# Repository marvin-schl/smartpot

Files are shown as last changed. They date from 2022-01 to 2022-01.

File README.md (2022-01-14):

# SmartPot

SmartPot ist ein RaspberryPi Projekt um einen smarten Blumentopf/Gewächshaus umzusetzen. Es werden alle für 
Pflanzen wichtigen Parameter (Temperatur, Luft-/Bodenfeuchtigkeit und Lichtstärke) gemessen und 
auf verschiedenen Wegen zur Verfügung stellt. Die Visualisierung der Daten kann über einen Webserver des 
Raspberry Pi´s aufgerufen und analysiert werden. Alternativ können die Sensorwerte auch per 
Telegram manuell erfragt werden. Außerdem können für alle Parameter kritische Schwellenwerte programmiert werden, bei deren 
Unter- bzw. Überschreiten eine Benachrichtigung über Telegram abgeschickt wird.
Im Folgenden wird die Umsetzung des Projektes detailliert dokumentiert, sodass mit Hilfe dieser 
Anleitung ein Nachbau des SmartPots möglich wird. Es werden alle Softwareeinrichtungsschritte von der Erstellung des Telegram Bots bis zur Node-RED Einrichtung erklärt. Außerdem werden Schaltpläne bereitgestellt welche auf die Softwareimplementationen angepasst sind. Zusätzlich zu den Schaltplänen wird ebenso ein Leiterplattenlayout, sowie alle benötigten Komponenten zum Bestücken der Leiterplatte mit einer Preisübersicht zur Verfügung gestellt.

Schaltungsseitig sind zur Zeit folgende Funktionalitäten implementiert:

- ein auf den RaspberryPi steckbares Shield mit integrierterm 12V/5V Linearregler zur Spannungsversorgung des Pi´s
- Anbindung eines Temperatur/Luftfeuchtigkeitssensors (DHT11/DHT22)
- Anbindung eines Bodenfeuchtigkeitssensors
- Anbindung eines Lichtsensors
- Drei schaltbare 12V/1,5A Leistungsausgänge mit PWM Unterstützung

Softwareseitig ist die aktuelle Version des SmartPots beinhaltet folgende Funktionen:

- _Temperatur_ messen, überwachen, auslesen und ausgeben
- _Luftfeuchtigkeit_ messen, überwachen,  auslesen und ausgeben
- _Bodenfeuchtigkeit_ messen, überwachen, auslesen und ausgeben
- _Lichtstärke_ messen, überwachen, auslesen und ausgeben
- Kommunikationsinterface über Telegram Web
- Node-RED Visualisierung der Sensorwerte (historisch/live)

Die Idee einen intelligenten Blumentopf zu entwickeln wurde durch zahlreiche Anleitungen aus dem
Web inspiriert (Bspw: [Automatisches Gewächshaus](https://tutorials-raspberrypi.de/automatisches-raspberry-pi-gewaechshaus-selber-bauen/)).

Der modulare Aufbau dieses Projektes eignet sich sehr gut für Gruppenarbeiten und kann dem
jeweiligen Wissensstand (Programmierung vom Raspberry Pi) durch Variation der
Funktionskomplexität angepasst werden.

In zukünftigen Versionen könnte unter einer optimierten Ausnutzung der verfügbaren Leistungsausgänge und Erweiterung von finanziellen Mitteln weitere Funktionen wie z.B. automatische Bewässerung, Lichtregelung sowie Belüftung realisiert werden, um so den Automatisierungsgrad weiter zu erhöhen.

## Gliederung

Diese Dokumentation glieder sich in folgende Schritte an denen unter Anderem die Inbetriebnahme des SmartPots erläutert wird:

1. Die Erstellung eines Telegram Bots 
2. Die Konfiguration des Telegram Bots für den SmartPot
3. Die Einrchtung von Node Red und der SmartPot Software selber 
    - 3.1 als manuelle Einichtung **oder**
    - 3.2  als automatische Einrchtung via docker und docker-compose
4. Die Bereitstellung der Schaltpläne und eines Leiterplattenlayout, zum Nachbau auf einem Bredboard oder zur Fertigung einer Leiterplatte, inklusive Stückliste aller benötigten Komponenten
5. Einer kurzen Übersicht der enthaltenen Klassen und Methoden 
6. Eine Übersicht, welche bekannten Schwachstellen und Verbesserungsideen für zukünftige Versionen des SmartPots existieren

## 1. Einrichtung des TelegramBots

Zunächst muss ein Chat mit dem Telegram-Bot „BotFather“ wie folgt erstellt werden:
Bei Telegram im Suchfeld „BotFather“ eingeben und unter Chats den BotFather auswählen.

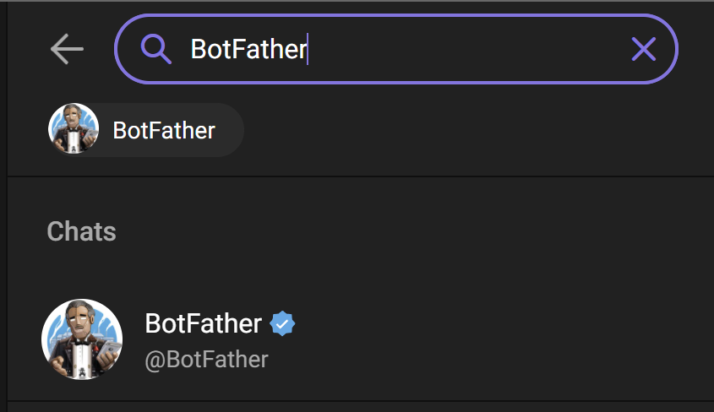
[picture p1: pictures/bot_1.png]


Im Chat des BotFathers kann nun ein Chatbot erstellt werden:

1. /newbot eingeben
2. Botname vergeben
3. Username vergeben
4. Bot-Token kopieren
5. Link für Chatbot anklicken

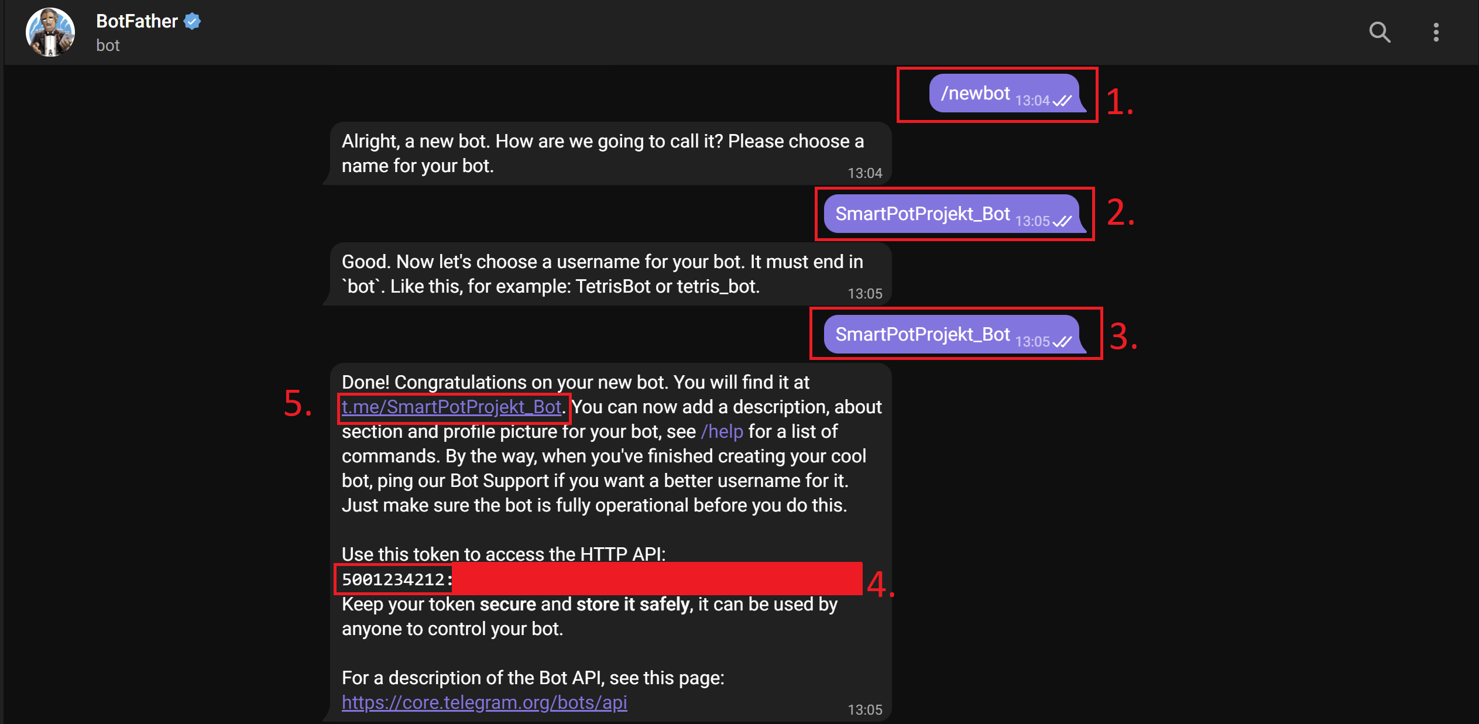
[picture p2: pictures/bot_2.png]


Zum Abfragen neuer Nachrichten muss im Browser folgende Website aufgerufen werden:

https://api.telegram.org/botReplaceThisWithTheBotFatherToken/getUpdates

In Telegram Web dem erstellten Chatbot eine Nachricht senden. 

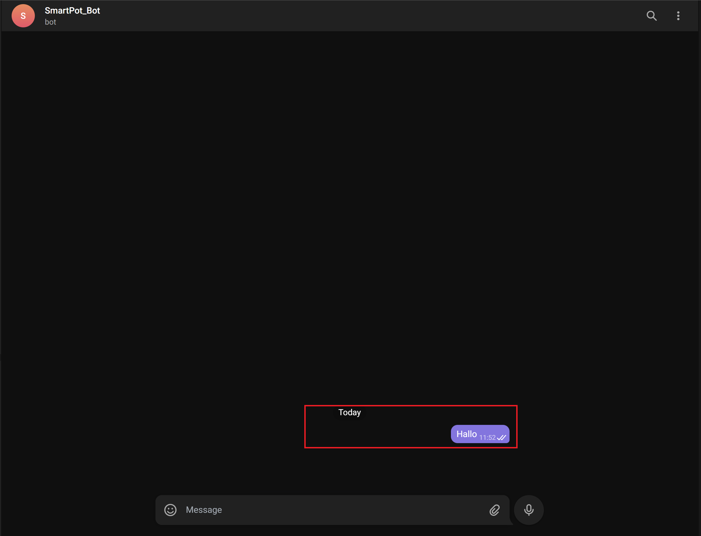
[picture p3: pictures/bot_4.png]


Nach Neuladen der Website kann nun aus der geschickten Nachricht die Chat-ID
ermittelt werden.



(Optional) Um den Chatbot einer Gruppe hinzufügen zu können, muss folgende Konfiguration im
BotFather vorgenommen werden:

1. /setprivacy eingeben
2. @Botname eingeben
3. Disable eingeben

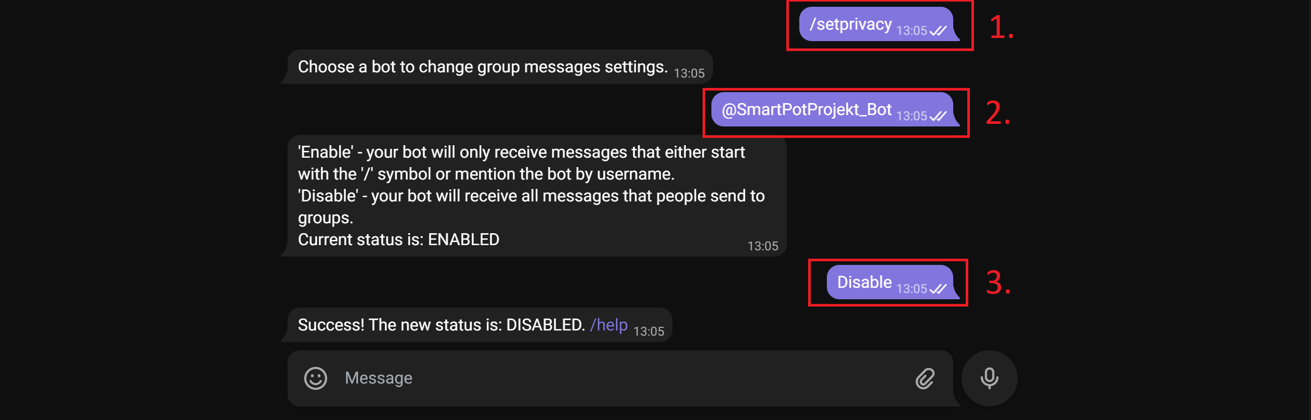
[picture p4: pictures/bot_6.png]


***Achtung:** Wenn sich der Chatbot in einer Gruppe befindet, muss die Chat-ID der Gruppe verwendet werden!*

## 2. Konfiguration des SmartPots

Es wird davon ausgegangen, dass auf dem RaspberryPi ein neu installiertes RaspianOS basierend auf Debian Buster installiert, ein Zugang zum Internet, sowie ein ssh Zugang vorhanden ist. Zunächst muss dieses Repository auf dem RaspberryPi geclonet werden:

    git clone https://git.haw-hamburg.de/aco732/smartpot.git

Für die Konfiguration steht eine smartpot.ini Datei zur Verfügung. 

``` ini
#############################################
# Smart Pot Version 1 - Configuration File  #
#############################################

[Telegram]

#Sets the telepot API token
chattoken = <your-token>

#Sets the telepot Chat-ID
chatid = <your-chat-id>

[Logging]

# Sets the loglevel, when not specified DEBUG is taken
# Possible Values: INFO, WARN, ERROR, DEBUG
level = DEBUG

# If set to 1 the logs will be printed on sys.stdout
stdout = 1

# Sets the logfile
# Comment out to deactivate Logfile
file = smartpot.log

[Soil Moisture]
# This section calibrates the soil moisture sensor. Keep in mind that any calibration action will only effect the
# python software. Depending on the Calibration it is possible that the Node-RED settings have to updated manually

# Calibration of the soil moisture sensor connected to adc channel 1.
# The calibrated output value is calculated from the Output value out [V]  follows:
#     calibrated_out = scaling*(out - offset)
# Calibration procedure:
#    1.) Set both Values to zero.
#    2.) Connect the sensor and make sure it's 100% dry.
#    3.) Measure the voltage offset and adjust offset_calibration value to get an calibrated_out of 0.
#    4.) Pull the sensor onto a defined soil moisture level.
#    5.) Adjust scaling in such a way that calibratet_out matches the desired value.
# Default calibration is between 0 and 100% -> max Voltage 1.9V -> sclaing=100/1.9=52.6315
offset = 0.0
scaling = 52.6315

# Defines the level at which calibrated_out is going into saturation. Comment out
# to disable saturation.
saturation = 100

# Defines the unit of the measured and calibrated value. Percent Symbols have to be escaped with another percent symbol.
unit = "%%"

[Light]
# This section calibrates the light sensor. Keep in mind that any calibration action will only effect the
# python software. Depending on the Calibration it is possible that the Node-RED settings have to updated manually.

# Calibration of the light sensor connected to adc channel 2.
# The calibrated ouput value is calculated from the Output value out [V] as follows:
#     calibrated_out = scaling*(out - offset)
# Calibration procedure:
#    1.) Set both Values to zero.
#    2.) Connect the sensor and make sure it's completly dark.
#    3.) Measure the voltage offset and adjust offset_calibration value to get an calibrated_out of 0.
#    4.) Pull the sensor onto a defined brightness level.
#    5.) Adjust scaling in such a way that calibratet_out matches the desired value.
# Default calibration is between 0 and 100% -> max Voltage 1.8V -> sclaing=100/1.9=55.555
offset = 0.0
scaling = 55.555

# Defines the level at which calibrated_out is going into saturation. Comment out
# to disable saturation.
saturation = 100

# Defines the unit of the measured and calibrated value. Percent Symbols have to be escaped with another percent symbol.
unit = "%%"

```

In der Konfiguationsdatei müssen nun der zuvor ermittelte Telegram API-Token unter chattoken und die ermittelte Chat-ID unter chatid eingetragen werden. Außerdem können das Log-Level, das Ausgabeformat der Logs und die Kalibration der analogen Sensoren angepasst werden. 

Alternativ kann das setup.sh Skript ausgeführt werden, um die Telegram Konfiguration durchzuführen. Auf die abschließende Frage, ob der SmartPot via docker-compose gestartet werden soll, muss in diesem Fall mit "n" geantwortet werden:

    bash setup.sh

## 3.1 manuelle Einrichtung des RaspberryPi's

Zuerst müssen über Python Paketmanager pip folgende Pakete installiert werden.

    pip3 install RPi.GPIO Adafruit_DHT smbus2 telepot

Desweiteren wird eine [Library für den MCP3426](https://github.com/coburnw/MCP342x) für den MCP3426 verwendet. Diese ist bereits in den Source Files enthalten.

### Einrichten von Node-RED

Das Installation von Node-RED erfolgt durch folgende Shell-Eingabe:

    bash <(curl -sL https://raw.githubusercontent.com/node-red/linux-installers/master/deb/update-nodejs-and-nodered) --node16

Das Node-RED Dashboard zur Visualisierung der Sensorwerte wird mit folgender Eingabe installiert:

    npm i node-red-dashboard

Zusätzlich müssen in den Node-RED Einstellungen Parameter konfiguriert werden:

    cd ~/.node-red
    nano settings.js

@Line 253: „//“ entfernen

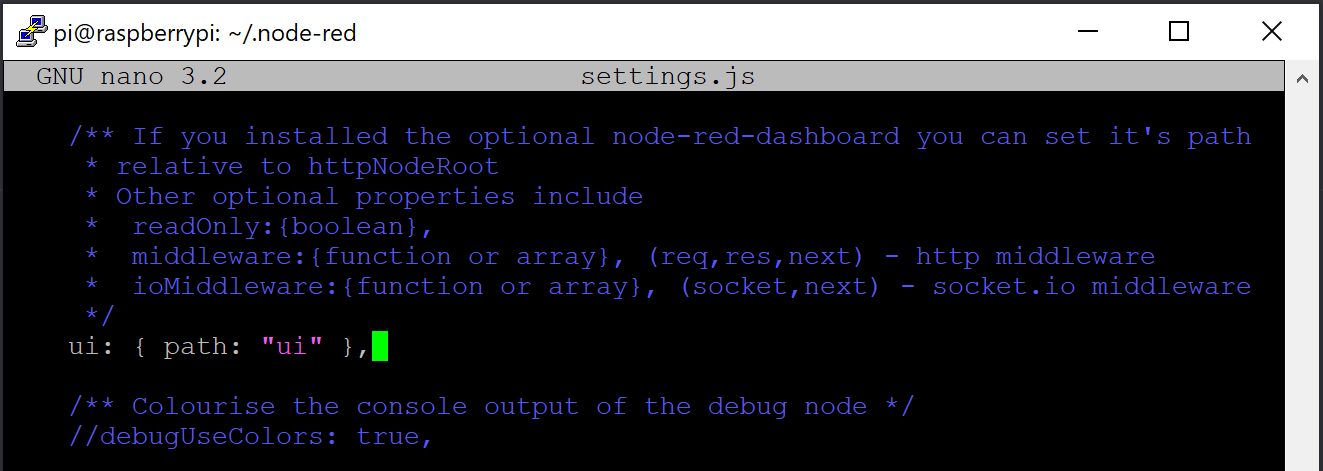
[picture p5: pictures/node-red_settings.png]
node-red_settings


Um Node-RED bei Systemstart automatisch auszuführen wird folgender Befehl verwendet:

    sudo systemctl enable nodered.service

Der Node-RED Editor ist über die IP-Adresse des Pi´s aufzurufen. Die IP wird wie folgt angezeigt:

    hostname -l

Node-RED ist standardmäßig auf Port 1880 erreichbar. Mit dem im vorherigen Schritt ermittelten <hostname> kann die Node-RED Konfiguration unter folgender Adresse im Interetbrowser aufgerufen werden:
    
    http://<hostname>:1880

Die vorbereitete Node-RED Visualisierung kann nun wie folgt installiert werden:

1. Menü-Reiter auswählen
2. Palette verwalten klicken

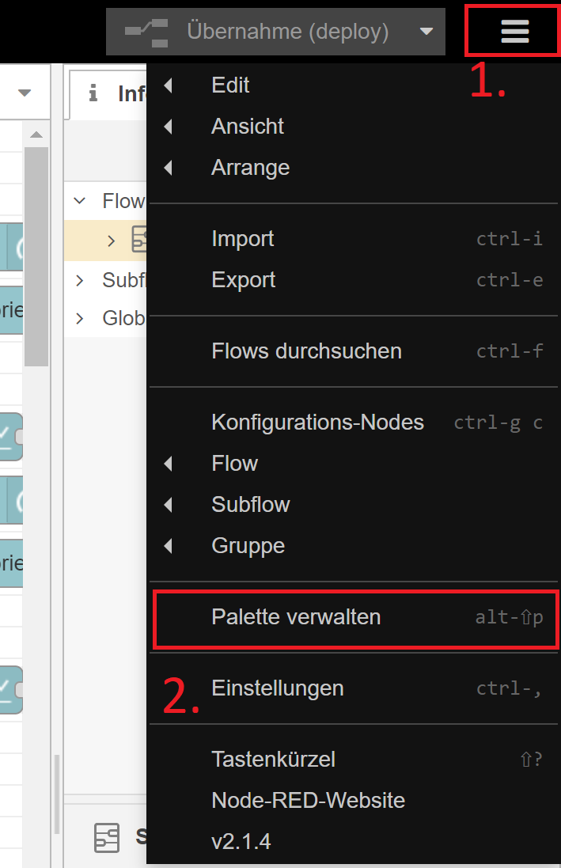
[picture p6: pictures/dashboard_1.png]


3. „Dashboard“ in Suchfeld eingeben
4. Auf „Installieren“ klicken

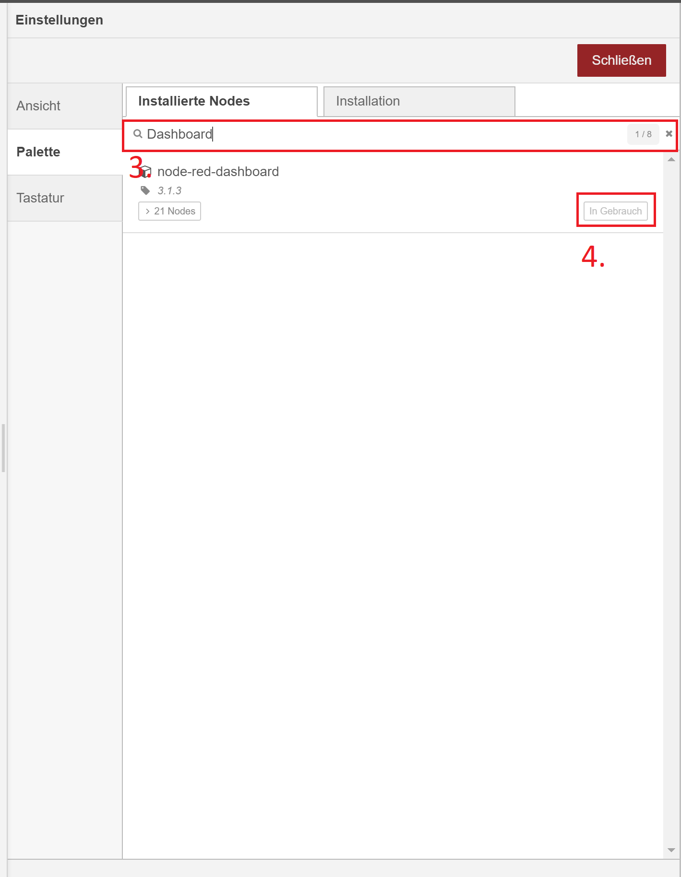
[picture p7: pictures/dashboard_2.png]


Die zur Verfügung gestellte Visualisierung des Node-RED Dashboards muss nun wie folgt kopiert werden:

    cp /home/pi/smartpot/resources/flows.json /home/pi/.node-red/lib/flows

Abschließend wird die flow-Datei in Node-RED importiert:

1. Menü-Reiter auswählen
2. Import klicken

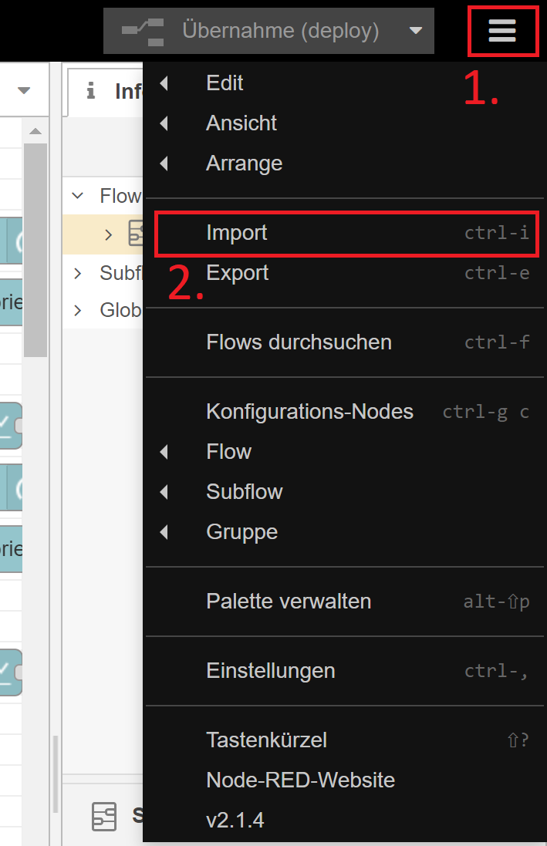
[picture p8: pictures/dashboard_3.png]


3. Lokal auswählen
4. „flows.json“ wählen

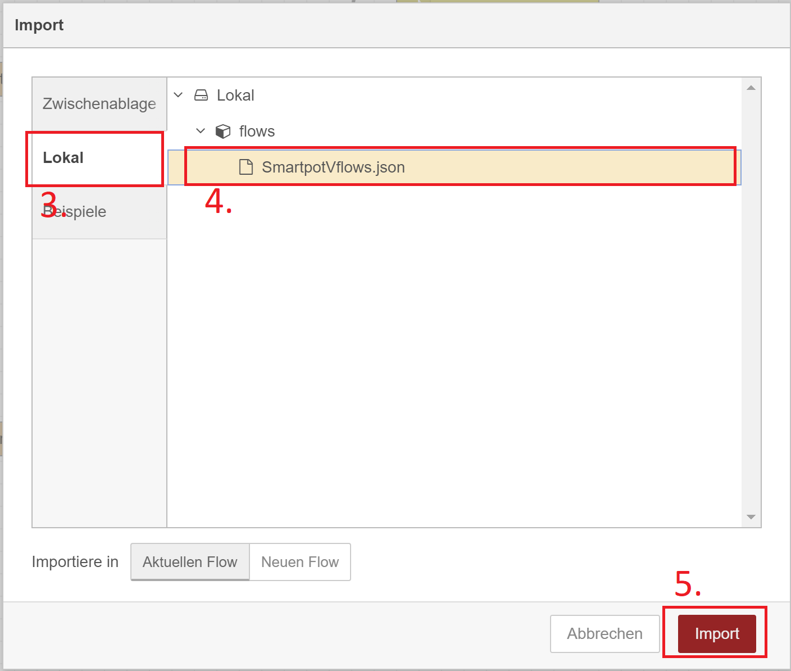
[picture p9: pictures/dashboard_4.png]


5. Auf „Import“ klicken
6. „Übernahme (deploy)“ klicken

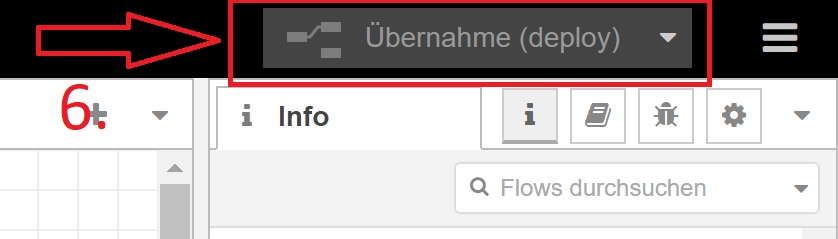
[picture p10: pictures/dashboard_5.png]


Die Visualisierung kann nun unter 

    http://<hostname>:1880/ui

erreicht werden.

## 3.2 automatische Einrichtung des RaspberryPi's via Docker

Falls docker und docker-compose bereits installiert sein sollten kann der nächste Schritt übersprungen werden und direkt mit "Starten der Smartpot Umgebung" fortgefahren werden.

### Einrichtung von docker und docker-compose

Für die Einrichtung von docker und docker-compose müssen folgende Befehle ausgeführt werden.

    sudo apt-get update
    curl -sSL https://get.docker.com | sh
    sudo apt-get install docker-compose
    sudo usermod -aG docker pi

Nachdem der letzte Befehl ausfgeführt worden ist muss der Pi neugstartet werden.

   sudo reboot

### Starten der Smartpot Umgebung

Vor dem ersten Start muss die setup.sh ausgeführt werden. Diese stellt sicher, dass die ini, log und csv Dateien vorhanden sind und die Telegrameinstellungen getätigt worden sind. Außerdem stellt diese sicher, dass die Container mit ausreichenden Rechten gestartet werden:
    
    bash setup.sh
    
Der SmartPot kann gleich im Anschluss darauf us dem Skript heraus gestartet werden. **Sollte der Start nicht direkt aus der setup.sh erfolgen muss zuerst ein Neustart oder Neulogin durchgeführt werden!**
Aus dem SmartPot Verzeichnis kann nach Neustart/Neulogin in Zukunft der SmartPot wie folgt gestartet werden:

    docker-compose up
    
Um den SmartPot als Hintergrunddienst laufen und automatisch starten zu lassen, muss zusätzlich das Flag -d/--detached (losgelöst) verwendet werden:
    
    docker-compose up -d

## 4. elektronischer Aufbau

Schaltplan des RaspberryPi Shields:

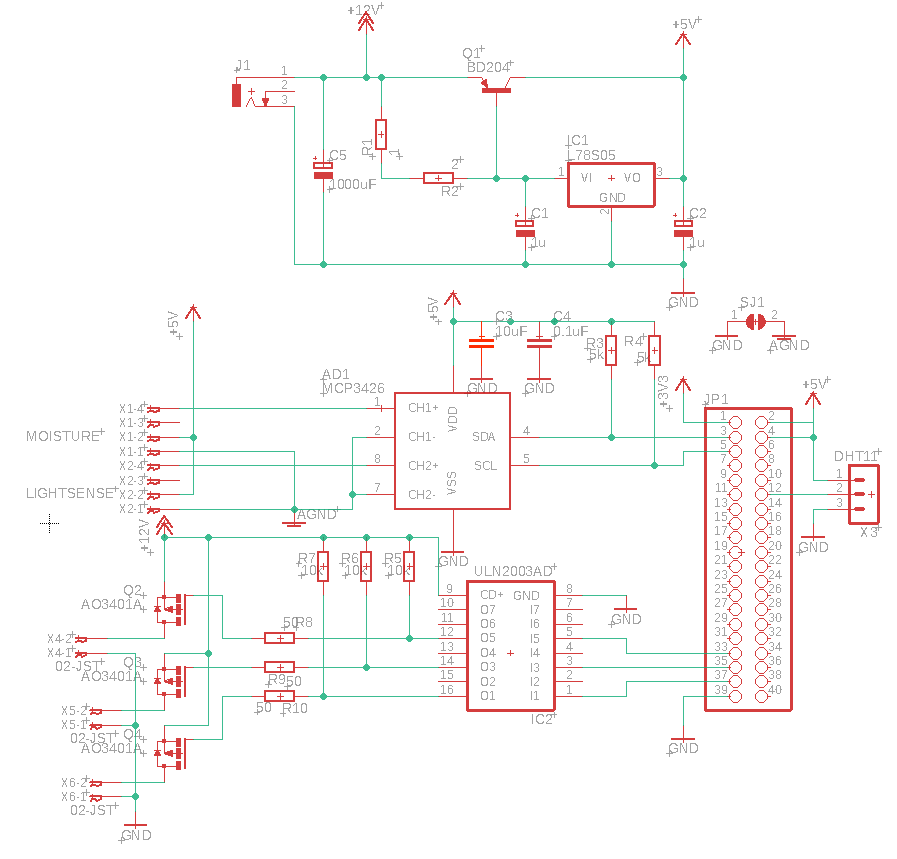
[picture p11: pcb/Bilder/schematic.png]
Schaltplan


Die Schaltung kann an einem handelsüblichen 12V Netzteil betrieben werden. Über einen 12V/5V Linearregler (uA78S05)
wird die Versorgnungsspannung für den RaspberryPi bereit gestellt. Auf dem Board ist eine dreipolige Buchsenleiste für einen DHT11 bzw DHT22 Sensor vorgesehen. Der Sensor kann einfach auf die Buchsenleiste gesteckt (Sensorseitig zur Platinenmitte zeigend) werden und per OneWire Protokoll ausgelesen werden. Für den analogen Lichtsensor und den analogen Bodenfeuchtigkeitssensors ist ein 2 Kanal Delta-Sigma AD-Wandler mit I2C Interface, der MCP3426, verbaut. Die drei Leistungsausgänge werden von drei P-Kanal Mosfets (AO3401A) geschaltet. Die Gate Signale werden durch einen Darlington-Array (ULN2003AD) getrieben, welches die Rohsignale des RaspberryPi verstärkt.
    
Für einen Betrieb des SmartPots über ein Bredboard muss in der aktuellen Version des SmartPots lediglich der DHT mit J1-12 und der MCP3426, zusätzlich zu seiner äußeren Beschaltung, mit den I2C-Pins J1-3 und J1-5 verbunden werden. Dann können die Sensoren analog zum o.g. Schaltplan ausgelesen werden. 
    
Die hier verwendeten analogen Sensoren geben Spannungen bis zu 4,2V  aus. Der MCP3426 kann an seinen differentiellen Eingängen jedoch nur Spannungen zwischen +-2,048V messen. Zur Reduktion der Eingangsspannung auf ein für den MCP3426 optimierten Spannungsniveau kann ein 1:1 Spannungsteiler (bswp: 10k-10k) verwendet werden. Dieser ist in den akuellen Schaltplänen und der Platine noch nicht vorgesehen. Aus diesem Grund wurde der Spannungsteiler in den beiden Sensorkabeln des Licht- und des Bodenfeuchtigkeitssensors verbaut.

Das dazugehörige Layout wurde wie folgt umgesetzt:

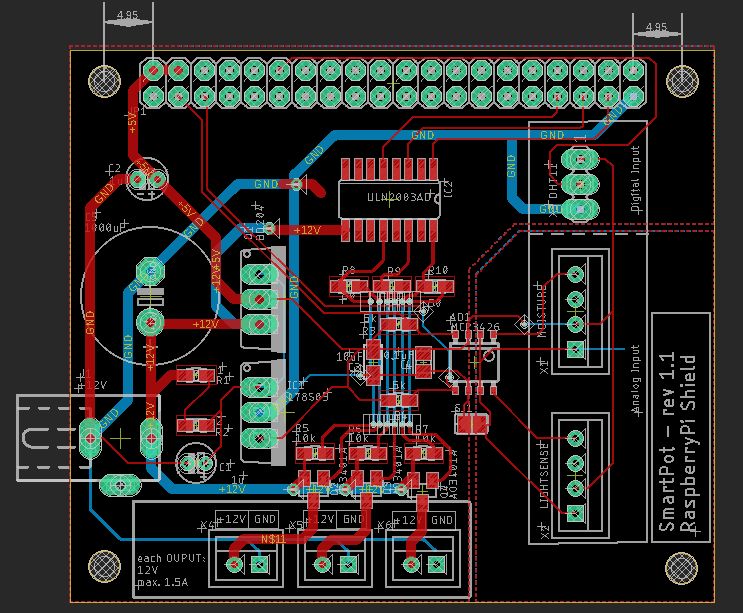
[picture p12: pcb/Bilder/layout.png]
Layout


### Stückliste

Position    |Bezeichnung                        | Anzahl  |Stückpreis €| Positionspreis €
------------|-----------------------------------|-------- |------------|-----------------
1           | RaspberryPi 3B                    |1        |39,4        | 39,4
2           | RaspberryPi Staking Header        |1        |1,6         | 1,60
3           | ULN2003AD                         |1        |0,75        | 0,75
4           | 10k Kohleschichtwiderstand        |4        |0,1         | 0,4
5           | RPI LK Kabel 50                   |2        |2,75        | 5,50
6           | MCP3426                           |1        |3,10        | 3,10
7           | uA78S05                           |1        |0,45        | 0,45
8           | BD204                             |1        |0,41        | 0,41
9           | AO3401A                           |3        |0,25        | 0,75
10          | Widerstand 0805 1,0               |1        |0,03        | 0,03
11          | Widerstand 0805 2,0               |1        |0,02        | 0,02
12          | Widerstand 0805 51,0              |3        |0,02        | 0,06
13          | Widerstand 0805 5k                |2        |0,03        | 0,06
14          | Widerstand 0805 10k               |3        |0,03        | 0,09
15          | Keramikkondensator 0805 100nF     |1        |0,02        | 0,02
16          | Tantalkondensator 1210 10uF       |1        |0,32        | 0,32
17          | Elektrolytkondensator 2mm 1uF     |2        |0,02        | 0,04
18          | Elektrolytkondensator 5mm 1mF     |1        |0,29        | 0,29
19          | JST XH2P ST Buchse                |3        |0,20        | 0,60
20          | JST XH4P ST Buchse                |2        |0,25        | 0,50
21          | 3fach Buchsenleiste 2,54mm        |1        |0,14        | 0,14
22          | DC Buchse 2.1mm                   |1        |1,20        | 1,20
23          | DHT11                             |1        |4,50        | 4,50
24          | Joy-It Linker Kit Lichtsensor     |1        |1,01        | 1,01
25          | Joy-it sen-Moisture Sensorkit     |1        |4,99        | 4,99
26          | Leiterplatte                      |1        |2,00        | 2,00
27          | Gesamt                            |         |            | 68,23

(Reichelt Preise beispielhaft, Stand 06.01.22)

## 5. Software Implementation

Nachfolgend soll eine Klassenreferenz augestellt werden. Die einen Überblick über die implementierten Klassen und deren Methoden gib. Für eine genauere Beschreibung bitte die Methoden Kommentare beachten. Dort werden die einzelnen Argumente genauer beschrieben. 

**monitor.HysteresisMonitor**:
Diese Klasse implementiert die nicht blockierende Überwachung einer Ausgangsgröße. Es kann eine Funktion übergeben werden, welche den zu überwachenden Wert zurückgibt, ein oberer Grenzwert und ein unterer Grenzwert. Außerdem kann für das überschreiten des oberen und das unterschreiten des unteren Grenzwerts jeweils eine Callback Funktion übergeben werden. Diese Klasse erbt von threading.Thread. Eine Beispielhafte Verwendung dieser Klasse ist in example.py gegeben.

Öffentliche Methoden:
- start()
- stop()
- run()

**mointor.TimeBasedMonitor**:
Diese Klasse implementiert die nicht blockierende Überwachung einer Ausgangsgröße. Es kann eine Funktion übergeben werden, die die zu überwachende(n) Größe(n) zurückgibt. Diese Klasse erbt von threading.Thread. Eine Beispielhafte Verwendung dieser Klasse ist in example.py gegeben.

Öffentliche Methoden:
- start()
- stop()
- run()

**src.smartpot.SmartPot**:
Diese Klasse implementiert eine physikalische Repräsentation des SmartPots an sich und dient als Interface zum Backend. Es sind drei Konstanten vorhanden SmarPot.smarpot.SmartPot.X4, SmarPot.smarpot.SmartPot.X5 und SmarPot.smarpot.SmartPot.X6. Diese referenzieren die Leistungsausgänge auf dem SmartPot Raspberry Shield rev 1.1 und können den output_* Methoden als pin übergeben werden.
Öffentliche Methoden:
- output_on(pin)
- output_off(pin)
- output_pwm_on(pin, freq, dc)
- output_pwm_off(pin)
- output_pwm_change_freq(pin, freq)
- output_pwm_change_dc(pin, dc)
- read_temperature()
- read_humidity()
- read_light_intensity()
- read_soil_moisture()

**src.dht.DHT**:
Diese Klasse wrapped die Adafruit_DHT Library und stellt einen objektorientierten Zugriff zur Verfügung. Es kann bei der instanziierung festgelgt werden ob es sich um einen DHT11 oder DHT22 handelt.

Öffentliche Methoden:
- read_temperature()
- read_humidity()

**src.adc.MCP3426**:
Diese Klasse wrapped die verwendete [MCP342x](https://github.com/coburnw/MCP342x) Library für die hier benötigete Anwendung.

Öffentliche Methoden:
- read_ch1()
- read_ch2()

**src.output.PowerOutputPin**:
Diese Klasse verwendendet das RPi.GPIO Modul und implementiert die Funktionen der Leistungsausgänge. 

Öffentliche Methoden
- on()
- off()
- start_pwm(freq, dc)
- stop_pwm()
- change_freq(freq)
- change_dc(dc)

## 6. Ausblick

Hier werden bekannte Schwächen der aktuellen Version des SmartPots sowies des dazugehörige Shield aufgelistet, welche in folgenden Versionen überarbeitet werden sollten.

- Der Linearregler auf der pcb wird bei Betrieb mit einem 12V Netzteil und hohen Stromverbräuchen des Raspberrys sehr warm. Hier wäre eine Spannungswandlung über einen Schaltregler zu bevorzugen.

- Beim Ausschalten der Leistungsausgänge, also wenn das Gatesignal der Ausgangsmosfets (Q2, Q3, Q4) von 0V auf 12V gezogen wird. Findet die Entladung der Gatekapazität im unbelaseten Zustand über die Pullup Widerstände (R5, R6, R7) statt. Dies führt zumidest im unbelasteten Zustand zu sehr hohen Abfallszeit des Ausgangssignals. Ein Ansatz wäre kleinere Pullup Widerstände zu verwenden auf Kosten einer höheren Stromaufnahme bei eingeschaltetem Ausgang. Ein anderer Ansatz wäre die verwendung einer richtigen Mosfet Endstufe.

- In dem jetzigen Design wurden die positiven und negativen Ch2 Eingangspins des MCP3426 vertauscht. Die folgliche invertiert gemessene Spannung wurde Softwareseitig kompensiert.
    
- Die Ausgangssignale der analog Sensoren sind bis zu 4V hoch. Der MCP3426 kann jedoch nur +-2,048V messen. Eine Lösuing wäre ein auf der Leiterplatte befindlicher 1:1 Spannungsteiler, ein anderer AD-Wandler oder besser an den AD-Wandler angepasste Sensoren.

- Eine Verbesserung des Automatisierungsgrades durch die Nutzung der Hardwareseitig implementierten Schaltfunktionen

- Eine Erweiterung der Node-RED Oberflächen, sodass nicht nur ein passives Monitoring sondern auch eine aktive Kontrolle des SmartPots möglich ist

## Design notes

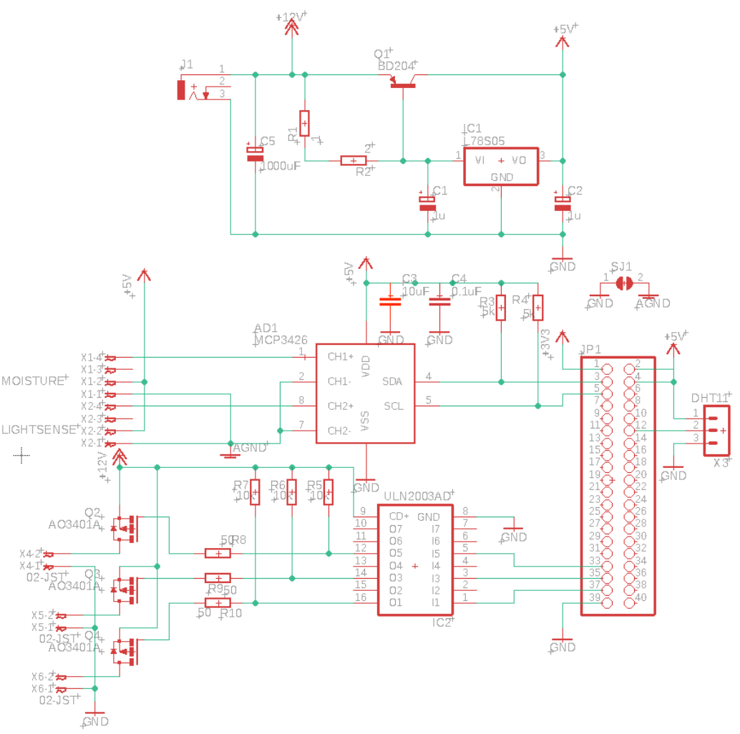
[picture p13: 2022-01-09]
pictures/schaltplan_platine.PNG

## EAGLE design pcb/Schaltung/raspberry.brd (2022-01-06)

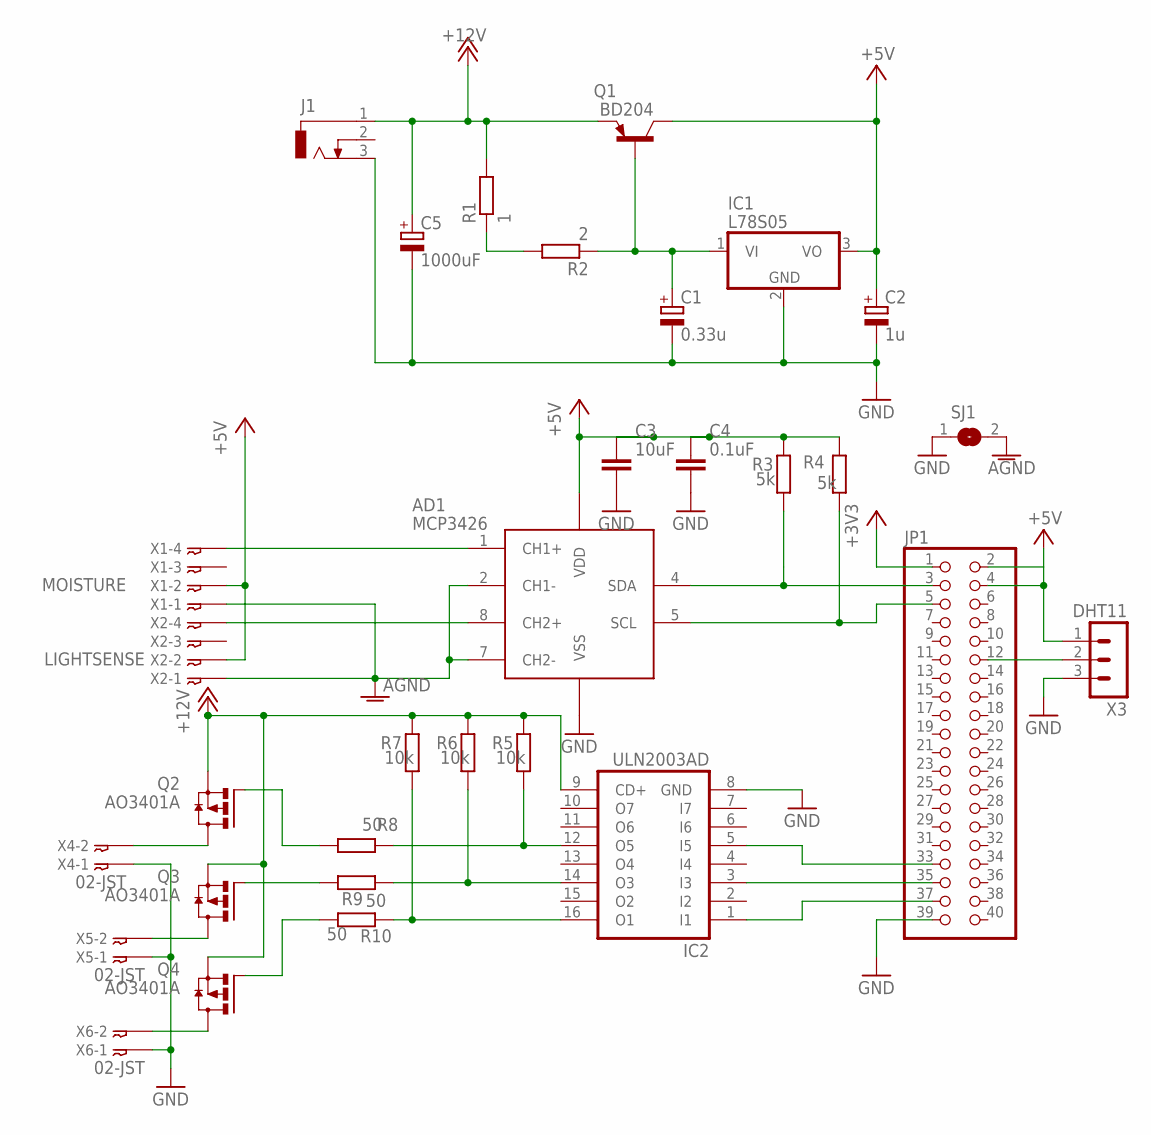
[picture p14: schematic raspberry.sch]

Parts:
AD1: MCP3426; SO-8
C1: 0.33u; E1,8-4
C2: 1u; E2-4
C3: 10uF; CAPM3216X180
C4: 0.1uF; CAPC2012X110
C5: 1000uF; E5-13
IC1: L78S05; TO220V
IC2: ULN2003AD; SO16
J1: DCJ0303
JP1: PINHD-2X20; 2X20
Q1: BD204; TO220V
Q2, Q3, Q4: AO3401A; SOT23
R1: 1; R0805W
R2: 2; R0805W
R3, R4: 5k; R0805W
R5, R6, R7: 10k; R0805W
R8, R9, R10: 50; R0805W
SJ1: SJ
X1: MOISTURE; B4B-XH
X2: LIGHTSENSE; B4B-XH
X3: DHT11; MA03-1
X4, X5, X6: 02-JST; B2B-XH

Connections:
+3V3: JP1.1
+5V: AD1.3 (VDD), C2.+, C3.1, C4.1, IC1.3 (VO), JP1.2, JP1.4, Q1.2 (C), R3.1, R4.1, X1.P$2, X2.P$2, X3.1
+12V: C5.+, IC2.9 (CD+), J1.1, Q1.3 (E), Q2.2 (S), Q3.2 (S), Q4.2 (S), R1.2, R5.1, R6.1, R7.1
AGND: AD1.2 (CH1-), AD1.7 (CH2-), SJ1.2, X1.P$1, X2.P$1
GND: AD1.6 (VSS), C1.-, C2.-, C3.2, C4.2, C5.-, IC1.2 (GND), IC2.8 (GND), J1.3, JP1.39, SJ1.1, X3.3, X4.P$1, X5.P$1, X6.P$1
GPIO18-DHT11-DATA: JP1.12, X3.2
unnamed: R1.1, R2.2
unnamed: AD1.4 (SDA), JP1.3, R3.2
unnamed: C1.+, IC1.1 (VI), Q1.1 (B), R2.1
unnamed: AD1.5 (SCL), JP1.5, R4.2
unnamed: AD1.8 (CH2+), X2.P$4
unnamed: AD1.1 (CH1+), X1.P$4
unnamed: IC2.1 (I1), JP1.37
unnamed: Q3.3 (D), X5.P$2
unnamed: Q4.3 (D), X6.P$2
unnamed: IC2.3 (I3), JP1.35
unnamed: Q2.3 (D), X4.P$2
unnamed: IC2.16 (O1), R7.2, R10.1
unnamed: Q2.1 (G), R8.2
unnamed: IC2.5 (I5), JP1.33
unnamed: Q3.1 (G), R9.2
unnamed: IC2.12 (O5), R5.2, R8.1
unnamed: IC2.14 (O3), R6.2, R9.1
unnamed: Q4.1 (G), R10.2

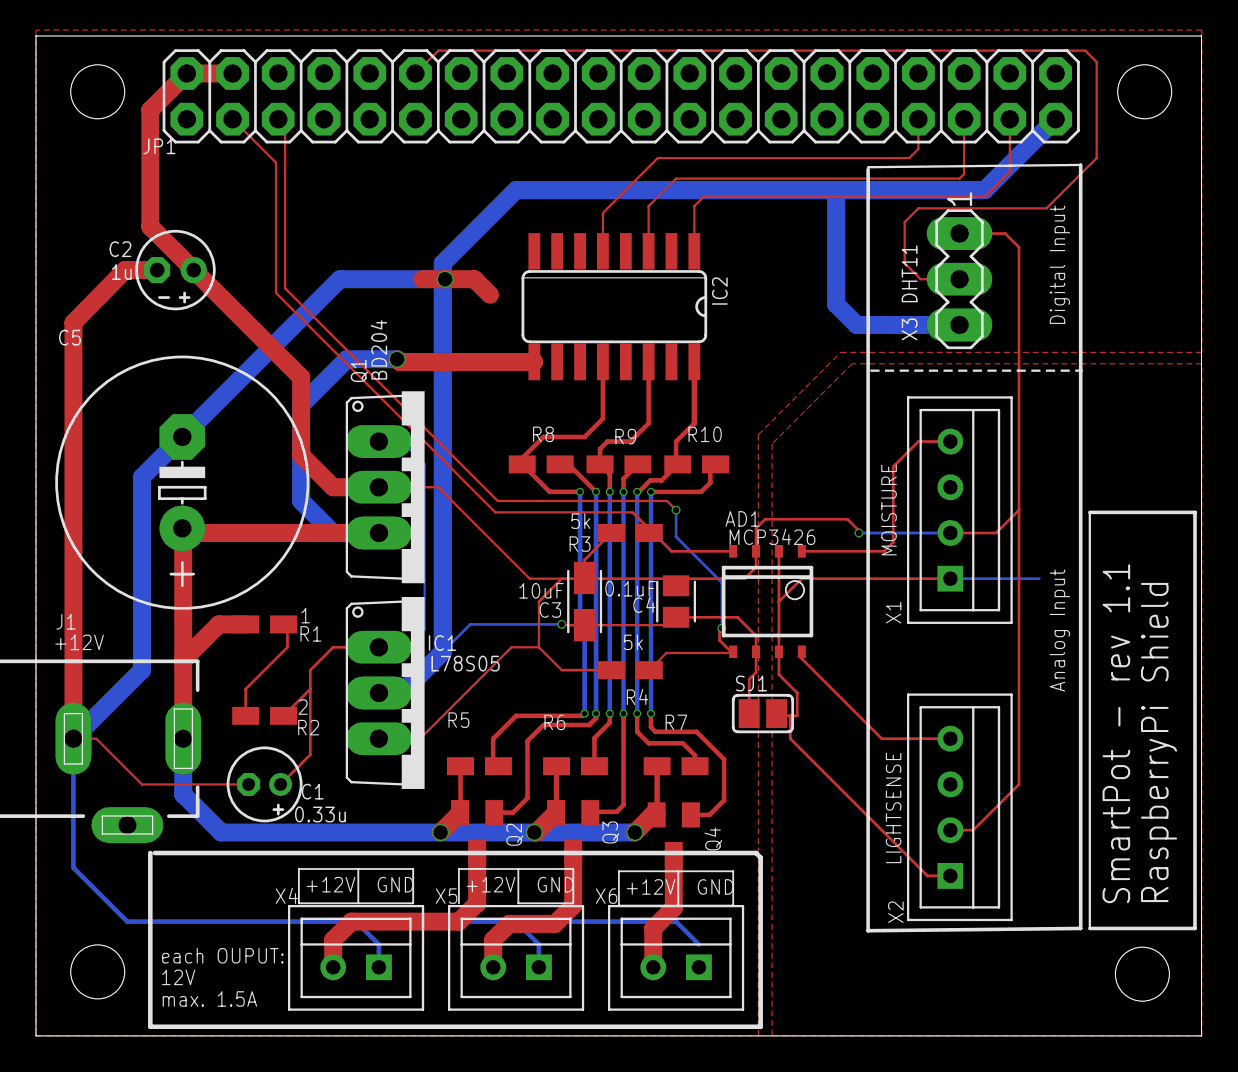
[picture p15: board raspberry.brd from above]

Board: 2 copper layers, 64.8 x 55.5 mm, 31 parts (0 on the bottom side), 23 nets.

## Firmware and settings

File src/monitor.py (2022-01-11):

import time
from datetime import datetime
from threading import Thread
from abc import ABC, abstractmethod
import logging
import configparser
#setup config
config = configparser.ConfigParser()
config.read("smartpot.ini")
#setup logger
# get root Logger
log = logging.getLogger()

class Monitor(Thread, ABC):
    """
    Implements a abstract monitor. This class handles every action all monitors have in common. Namely this is the
    retrieving of the monitored value, retrieving a timestamp and waiting the cycle time repeatedly until the stop method
    is called.
    """
    def __init__(self, name, getter, cycle_time):
        """
        Initilizes a new Monitor.
        :param name: A String representation of the value that is monitored. Mainly for logging purposes.
        :param getter: A callable which return value should be the value of the monitored variable.
        :param cycle_time: Time to wait beween retrieving new values in seconds. Default value is 0.1s.
        """
        super().__init__()
        self.__getter = getter
        self.__name = name
        self.__cycle_time = cycle_time
        self.__running = False

    @property
    def running(self):
        return self.__running

    @property
    def name(self):
        return self.__name

    def start(self):
        """
        Starts the run() method in a new Thread.
        :return: None
        """
        self.__running = True
        log.info(type(self).__name__.__str__() + " - Starting Monitor for " + self.__name + " in a new Thread...")
        super().start()

    def stop(self):
        """
        Stops the running Monitor Thread.
        :return: None
        """
        self.__running = False
        log.info(type(self).__name__.__str__() + " - Stopping Monitor for " + self.__name + "...")

    def run(self,*args,**kwargs):
        #do as long as self.__running is true
        while self.__running:
            val = self.__getter()
            now = datetime.now()
            self.handle(val,now)
            # wait the cycle time until next value is retrieved
            time.sleep(self.__cycle_time)
        log.info(type(self).__name__.__str__() + " - Monitor for " + self.__name + " stopped...")

    @abstractmethod
    def handle(self, val, now):
        """
        The specific handling of the monitored value. Has to be implemented by the subclass.
        :param val: Monitored Value
        :param now: Timestamp
        :return:
        """
        pass

class HysteresisMonitor(Monitor):

    def __init__(self,name,getter,thres,callback_up_thres,lower_thres = None,callback_lw_thres = None,cycle_time = 0.1):
        """
        Initilizes a new HysteresisMonitor class. A callback is called by this class as soon as a defined threshold value
        is exceeded. Optionally a second callback can be passed when the monitored value falls below a lower threshold.
        :param name: A String representation of the value that is monitored. Mainly for logging purposes.
        :param getter: A callable which return value should be the value of the monitored variable.
        :param thres: The upper threshold.
        :param callback_up_thres: A callable which is called when getter() > thres.
                                    Signature should be: `callback_up_thres(name, val, thres, timestamp)`
        :param lower_thres: (optionally) A lower threshold value. Default value is equal to thres.
        :param callback_lw_thres: (optionally) A callable which is called when getter() < lower_thres. When not passed nothing is executed.
                                    Signature should be: `callback_lw_thres(name, val, thres, timestamp)`
        :param cycle_time: (optionally) Time to wait beween retrieving new values in seconds. Default value is 0.1s.
        """
        log.info("Initiliazing Monitor for "+ name + ".")
        super().__init__(name, getter, cycle_time)
        self.__thres = thres
        self.__lw_thres = self.__thres if lower_thres == None else lower_thres
        if self.__lw_thres > self.__thres:
            log.warning(type(self).__name__.__str__() + " - Lower Threshold for Value " + self.name + " of "
                            + str(self.__lw_thres)+ "is greater than upper threshold of " + str(self.__thres) + ".")
        self.__callback_up_thres = callback_up_thres
        self.__callback_lw_thres = callback_lw_thres
        self.__reported = False
        log.info(type(self).__name__.__str__() + " - Successfully initilized " + self.name + " Monitor.")


    def handle(self, val, now):
        """
        Hanlde method which is does the actual handling of the monitored value.
        :param val: Monitored Value
        :param now: Timestamp
        :return: None
        """
        if val > self.__thres and self.__reported == False:
            # do this if self.__thres is exceeded for the first time, do some logging
            log.info(type(self).__name__.__str__() + " - Value "+ self.name + "=" +str(val)+ "passed upper threshold of " + str(self.__thres) + " at " + str(now) +".")
            #call the callback
            self.__callback_up_thres(now, val, self.__thres, self.name)
            #set reported to True to make sure that the callback is not called every single cycle while val is greater than threshold
            self.__reported = True
        if val < self.__lw_thres and self.__reported == True:
            # do this if a exceed was reported and the val falls bellow lower threshold
            # reset the reported value so next up_threshold exceed will be reported and do some logging
            self.__reported = False
            log.info(type(self).__name__.__str__() + " - Value "+ self.name + "=" + str(val) + "passed upper threshold of " + str(self.__lw_thres) + " at " + str(now) +".")
            # if a callback is provided for this case, execute in
            if self.__callback_lw_thres != None:
                self.__callback_lw_thres(now, val, self.__lw_thres, self.name)


class TimeBasedMonitor(Monitor):

    def __init__(self, name, getter, callback, cycle_time):
        """
        Initilizes a new TimeBasedMonitor. A TimeBasedMonitor monitors a specific variable by retrieving its value
        in defined time steps.

        :param name: A String representation of the value that is monitored. Mainly for logging purposes.
        :param getter: A callable which return value should be the value of the monitored variable.
        :param callback: A callback functioin which is called every cycle.
                            Signature should be: `callback(name, val, timestamp)`
        :param cycle_time: Time to wait beween retrieving new values in seconds.
        """
        log.info(type(self).__name__.__str__() + " - Initiliazing Monitor for "+ name + ".")
        super().__init__(name, getter, cycle_time)
        self.__callback = callback
        log.info(type(self).__name__.__str__() + " - Successfully initilized " + name + " Monitor.")


    def handle(self, val, now):
        """
        Hanlde method which is does the actual handling of the monitored value.
        :param val: Monitored Value
        :param now: Timestamp
        :return: None
        """
        #do some logging and exceute the callback
        log.info(type(self).__name__.__str__() + " - Read Value for " + self.name + "="+str(val)+" at "+ str(now)+".")
        self.__callback(now, val, self.name)


if __name__=="__main__":

    x = 0
    thres = 12

    def get_x():
        return x

    def callback(timestamp, value, threshold, name):
        print("Value "+ name + "=" +str(value)+ "passed threshold of " + str(threshold) + " at " + str(timestamp) +".")

    def callback2(now, val, name):
        print(str(now) + " - " +name+"="+str(val))

    log.info("Starting Monitors...")
    m = HysteresisMonitor("x", get_x, thres, callback, callback_lw_thres=callback)
    m2 = TimeBasedMonitor("x", get_x, callback2, 1)
    m.start()
    m2.start()


    log.debug("Starting counting up...")
    while x < 14:
        x += 0.3
        time.sleep(0.2)
    log.debug("Starting counting down...")
    while x >= 0:
        x -= 0.3
        time.sleep(0.2)

    m.stop()
    m2.stop()
    m.join()
    m2.join()

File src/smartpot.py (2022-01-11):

from src.adc import MCP3426
from src.dht import DHT
from src.output import PowerOutputPin
from src import logging_conf_setup
import logging
import configparser

#setup logger for the first time
logging_conf_setup.setup()
#setup config
config = configparser.ConfigParser()
config.read("smartpot.ini")
#setup logger
# get root Logger
log = logging.getLogger()


class SmartPot:
    """
    This class represents a physical SmartPot rev1.1. It handles the simple functions like controlling single outputs,
    reading temperature, humidity, light intensity and soil moisture values.
    """

    X4 = 13
    X5 = 19
    X6 = 26
    pin_names = {13:"X4",19: "X5" ,26: "X6"}

    def __init__(self, dht_type = "DHT11"):
        """
        Creates a new instance of a SmartPot. The implementation is threadsafe.
        :param dht_type: (optional) "DHT11" or "DHT22" depending on the connected DHT sensor. Default Value is "DHT11".
        """
        power_pins = [SmartPot.X4, SmartPot.X5, SmartPot.X6]
        dht_pin = 18
        adc_bus = 1
        log.info(type(self).__name__ + " - Initializing ADC on Bus Number " + adc_bus.__str__())
        self.__adc = MCP3426(adc_bus)
        log.info(type(self).__name__ + " - Initializing "+dht_type+" on pin "+dht_pin.__str__()+"...")
        self.__dht = DHT(dht_pin, dht_type)

        log.info(type(self).__name__ + " - Initializing PowerOutputPins X4,X5 and X6...")
        self.__power_pins = {}
        for pin in power_pins:
            self.__power_pins[pin] = PowerOutputPin(pin)
        log.info(type(self).__name__ + " - SmartPot initalized")


    def output_on(self, pin):
        """
        Sets an power output HIGH
        :param pin: SmartPot.X4, SmartPot.X5 or SmartPot.X6
        :return: None
        """
        log.info(type(self).__name__ + " - Turning PowertOuput "+ SmartPot.pin_names[pin]+" on.")
        self.__power_pins[pin].on()

    def output_off(self, pin):
        """
        Sets an power output LOW
        :param pin:  SmartPot.X4, SmartPot.X5 or SmartPot.X6
        :return: None
        """
        log.info(type(self).__name__ + " - Turning PowertOuput "+SmartPot.pin_names[pin]+" off.")
        return self.__power_pins[pin].off()

    def output_pwm_on(self, pin, freq, dc):
        """
        Starts a PWM on an power output.
        :param pin: SmartPot.X4, SmartPot.X5 or SmartPot.X6
        :param freq: Frequency in Hertz
        :param dc: Duty Cycle in percent
        :return: None
        """
        log.info(type(self).__name__ + " - Turning PWM at "+SmartPot.pin_names[pin]+" on. f=" +str(freq)+"Hz, dc="+str(dc)+"%")
        return self.__power_pins[pin].start_pwm(freq, dc)

    def output_pwm_off(self, pin):
        """
        Stops a PWM on an power output
        :param pin: SmartPot.X4, SmartPot.X5 or SmartPot.X6
        :return: True if successfull, False if no PWM was started yet
        """
        log.info(type(self).__name__ + " - Turning PWM at "+SmartPot.pin_names[pin]+" off.")
        return self.__power_pins[pin].stop_pwm()

    def output_pwm_change_freq(self, pin, freq):
        """
        Changes PWM Frequency of an power output
        :param pin: SmartPot.X4, SmartPot.X5 or SmartPot.X6
        :param freq: New frequency in Hertz
        :return: True if successfull, False if no PWM was started yet
        """
        log.info(type(self).__name__ + " - Changing  PWM Frequency at "+SmartPot.pin_names[pin]+" to f="+str(freq)+"Hz.")
        return self.__power_pins[pin].change_freq(freq)

    def output_pwm_change_dc(self, pin, dc):
        """
        Changes the duty cycle of an power output
        :param pin: SmartPot.X4, SmartPot.X5 or SmartPot.X6
        :param dc: New duty cycle in percent
        :return: True if successfull, False if no PWM was started yet
        """
        #no dc cycle change logging because -> eventually overloading the logfile
        #log.debug("Changing PWM DC at "+SmartPot.pin_names[pin]+" to dc="+str(dc)+"%.")
        return  self.__power_pins[pin].change_dc(dc)

    def read_temperature(self):
        """
        Reads the temperature of an connected DHT sensor.
        :return: Temperature in degree celsius
        """
        log.info(type(self).__name__ + " - Start temperature measurement.")
        temp = self.__dht.read_temperature()
        log.info(type(self).__name__ + " - Temperature measurement finished at "+str(temp)+"'C.")
        return temp

    def read_humidity(self):
        """
        Reads the humidity  of an connected DHT sensor.
        :return: relative humidity in percent
        """
        log.info(type(self).__name__ + " - Start humidity measurement.")
        hum = self.__dht.read_humidity()
        log.info(type(self).__name__ + " - Humidity measurement finished at "+str(hum)+"%.")
        return hum

    def read_light_intensity(self):
        """
        Reads the value of the light intensity sensor and applies calibration of INI File.
        :return: Light intensity value according to calibration values in INI File.Default
        calibration should return percentage of maximum measureable light intensity value.
        """
        log.info(type(self).__name__ + " - Start light intensity measurement.")

        #get the adc value in volts
        intensity = self.__adc.read_ch2()

        if intensity != -999:
            # calibrate
            scale = float(config["Light"]["scaling"])
            offset = float(config["Light"]["offset"])
            intensity = scale*(intensity - offset)

        #apply saturation if configured
        if "saturation" in config["Light"]:
            saturation = float(config["Light"]["saturation"])
            intensity = intensity if intensity < saturation else saturation

        log.info(type(self).__name__ + " - Light intensity measurement finished at "+str(intensity)+" %.")
        return intensity

    def read_soil_moisture(self):
        """
        Reads the value of the soil moisture sensor.
        :return: relative soil moisture in percent
        """
        log.info(type(self).__name__ + " - Start soil moisture measurement.")

        #get the adc value in volts
        moisture = self.__adc.read_ch1()

        if moisture != -999:
            # calibrate
            scale = float(config["Soil Moisture"]["scaling"])
            offset = float(config["Soil Moisture"]["offset"])
            moisture = scale*(moisture - offset)

        #apply saturation if configured
        if "saturation" in config["Soil Moisture"]:
            saturation = float(config["Soil Moisture"]["saturation"])
            moisture = moisture if moisture < saturation else saturation

        log.info(type(self).__name__ + " - Soil moisture measurement finished at "+str(moisture)+"%.")

        return moisture

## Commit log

2021-12-27 corrected names of output pins corresponding to naming on shield
    [smartpot.py]
2021-12-27 corrected dht pin from 21 to 18
    [smartpot.py]
2021-12-27 debugging adc channel2
2021-12-28 debugging adc
2021-12-29 added threadsafe locks in classes where hardware access happens
2021-12-29 fixed some syntax errors
    [smartpot.py]
2022-01-06 added schmeatics,gerber files and layout
    [raspberry.brd, raspberry.sch]
2022-01-07 adjusted unit of soil moisture and light sensor output
2022-01-07 NodeRed Flow Visualisierung
2022-01-07 Logging und TelegramBot Monitor Stops hinzugefügt
    [Logging.csv]
2022-01-08 adjusted max values of soil moisture and light sensor
2022-01-08 Jason Node Red Datei Updated
    [Logging.csv]
2022-01-08 Node Red Flow änderung
    [Logging.csv]
2022-01-08 Jason Datei Charts korregiert
    [Logging.csv]
2022-01-09 Kommentare in Telegramprogramm hinzugefügt
    [Logging.csv]
2022-01-10 reafactored logging
    [Logging.csv]
2022-01-10 debugging calibration
2022-01-10 changed Chart Reset Button to clear Logging.csv file and not to delete it
2022-01-11 init commit
    [Logging.csv]
